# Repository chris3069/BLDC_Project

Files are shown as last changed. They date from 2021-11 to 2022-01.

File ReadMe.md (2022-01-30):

# BLDC source code and electronics

# Electronics
## Schematics:

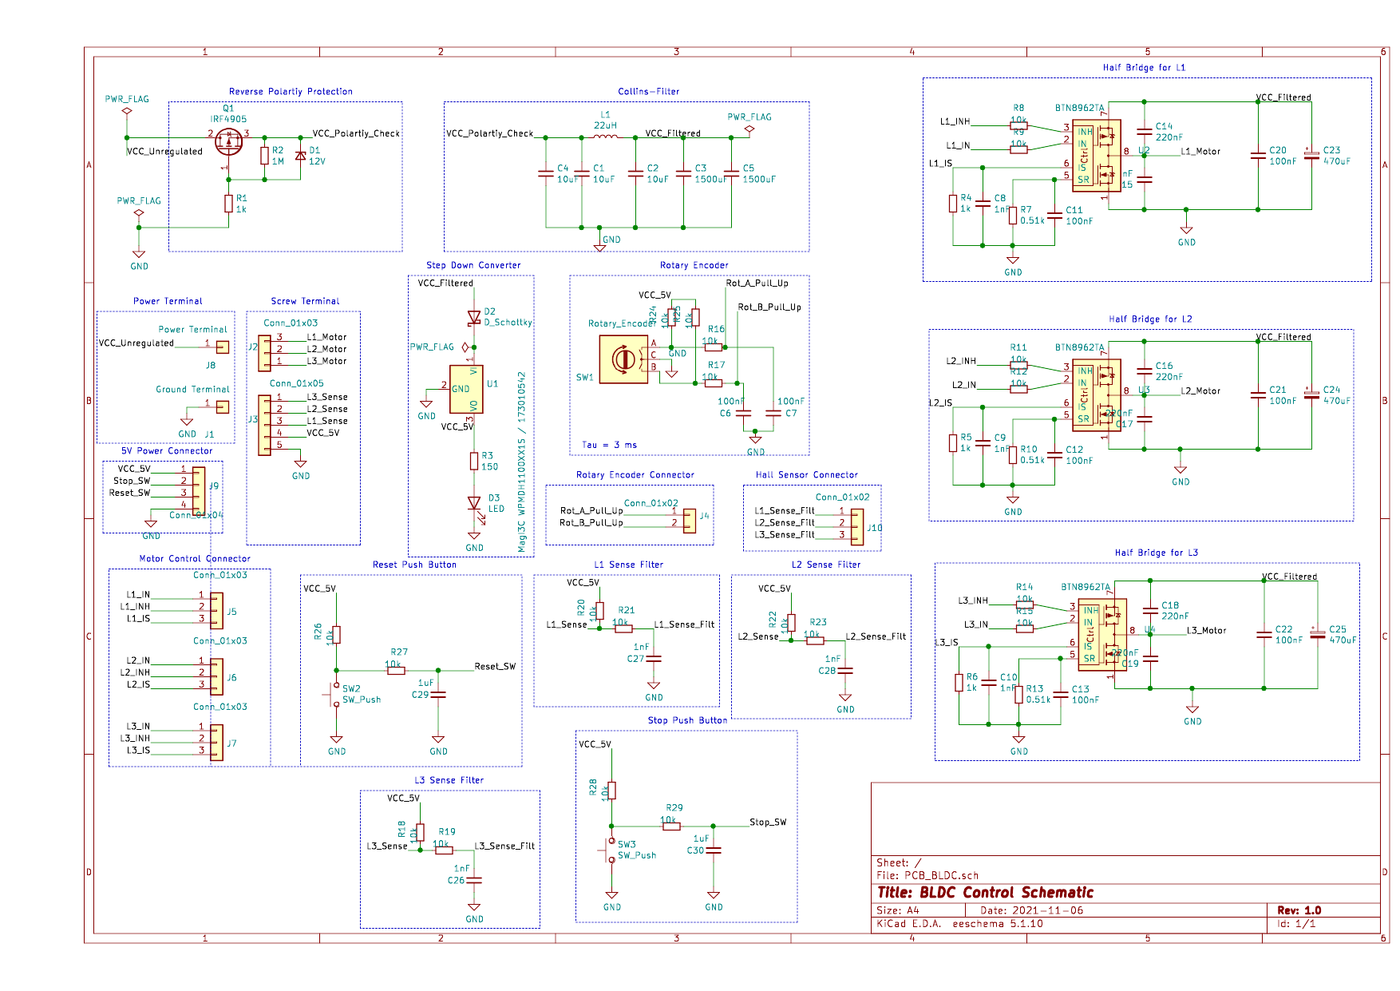
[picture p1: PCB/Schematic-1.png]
Schematic


## Design and Routing

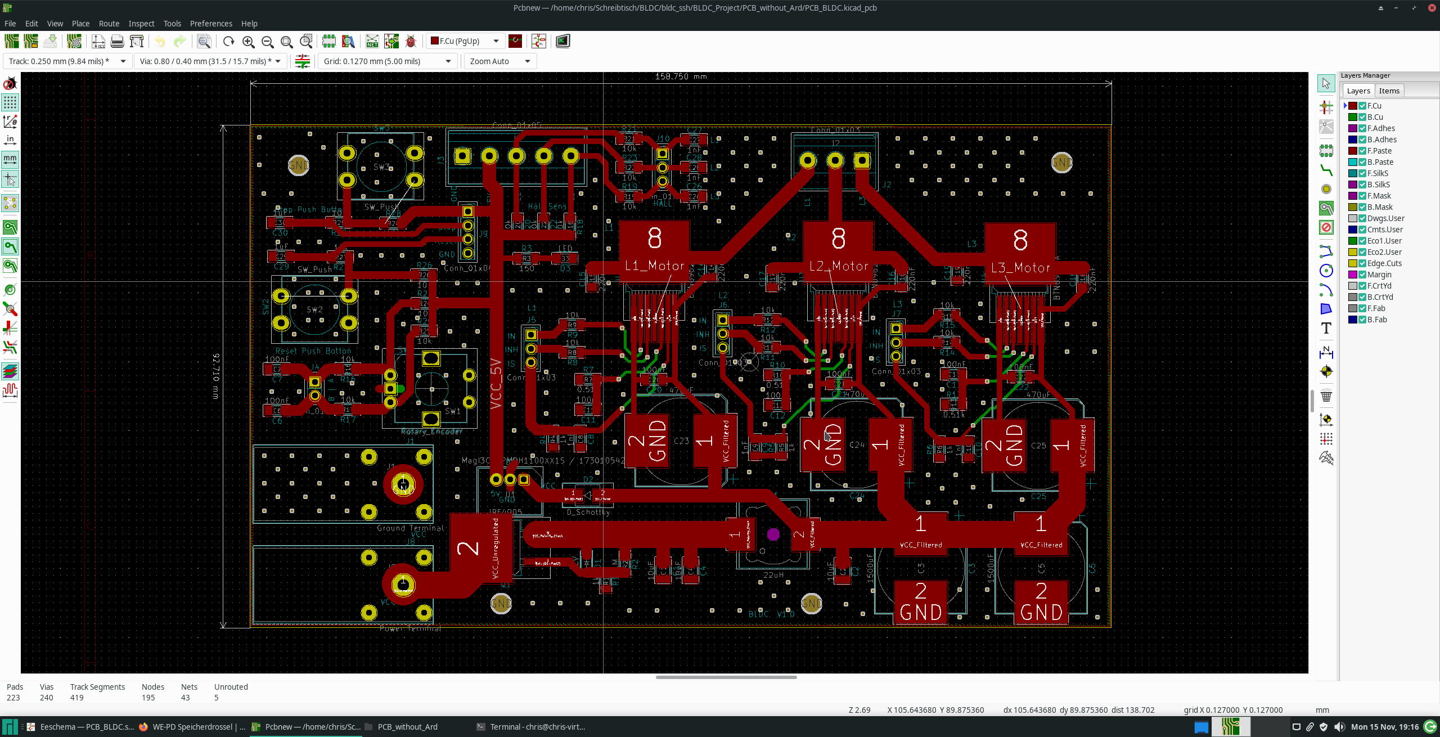
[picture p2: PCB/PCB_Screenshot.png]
PCB_Routing 2D Schematic


## 3D Electric Design:
### Frontside 
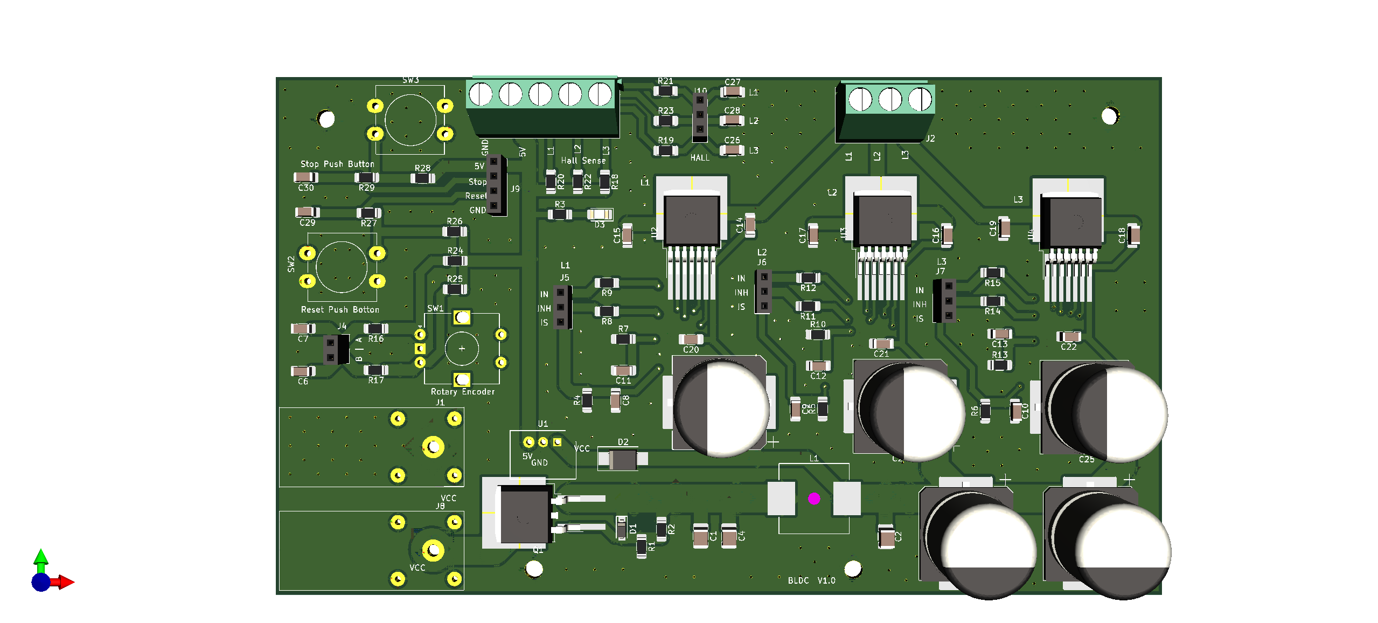
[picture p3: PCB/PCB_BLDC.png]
Frontside

### Backside
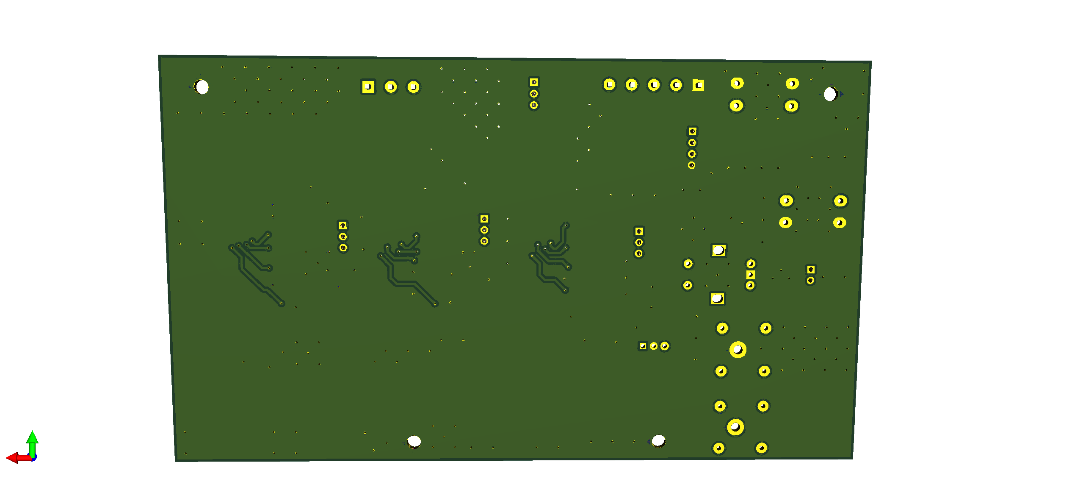
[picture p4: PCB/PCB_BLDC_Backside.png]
Backside


# SW

## Open Loop Control

## Closed Loop Control

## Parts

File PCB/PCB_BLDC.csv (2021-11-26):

Source: | /home/chris/Schreibtisch/BLDC/bldc_ssh/BLDC_Project/PCB_without_Ard/PCB_BLDC.sch
Date: | Mon 15 Nov 2021 06:43:22 PM CET
Tool: | Eeschema 5.1.10
Generator: | /usr/share/kicad/plugins/bom_csv_grouped_by_value.py
Component Count: | 81
Individual Components:
Item | Qty | Reference(s) | Value | LibPart | Footprint | Datasheet
 |  | C1 | 10uF | Device:C_Small | Capacitor_SMD:C_1210_3225Metric_Pad1.33x2.70mm_HandSolder | ~
 |  | C2 | 10uF | Device:C_Small | Capacitor_SMD:C_1210_3225Metric_Pad1.33x2.70mm_HandSolder | ~
 |  | C3 | 1500uF | Device:C_Small | Capacitor_SMD:CP_Elec_16x17.5 | ~
 |  | C4 | 10uF | Device:C_Small | Capacitor_SMD:C_1210_3225Metric_Pad1.33x2.70mm_HandSolder | ~
 |  | C5 | 1500uF | Device:C_Small | Capacitor_SMD:CP_Elec_16x17.5 | ~
 |  | C6 | 100nF | Device:C_Small | Capacitor_SMD:C_1206_3216Metric_Pad1.33x1.80mm_HandSolder | ~
 |  | C7 | 100nF | Device:C_Small | Capacitor_SMD:C_1206_3216Metric_Pad1.33x1.80mm_HandSolder | ~
 |  | C8 | 1nF | Device:C_Small | Capacitor_SMD:C_1206_3216Metric_Pad1.33x1.80mm_HandSolder | ~
 |  | C9 | 1nF | Device:C_Small | Capacitor_SMD:C_1206_3216Metric_Pad1.33x1.80mm_HandSolder | ~
 |  | C10 | 1nF | Device:C_Small | Capacitor_SMD:C_1206_3216Metric_Pad1.33x1.80mm_HandSolder | ~
 |  | C11 | 100nF | Device:C_Small | Capacitor_SMD:C_1206_3216Metric_Pad1.33x1.80mm_HandSolder | ~
 |  | C12 | 100nF | Device:C_Small | Capacitor_SMD:C_1206_3216Metric_Pad1.33x1.80mm_HandSolder | ~
 |  | C13 | 100nF | Device:C_Small | Capacitor_SMD:C_1206_3216Metric_Pad1.33x1.80mm_HandSolder | ~
 |  | C14 | 220nF | Device:C_Small | Capacitor_SMD:C_1206_3216Metric_Pad1.33x1.80mm_HandSolder | ~
 |  | C15 | 220nF | Device:C_Small | Capacitor_SMD:C_1206_3216Metric_Pad1.33x1.80mm_HandSolder | ~
 |  | C16 | 220nF | Device:C_Small | Capacitor_SMD:C_1206_3216Metric_Pad1.33x1.80mm_HandSolder | ~
 |  | C17 | 220nF | Device:C_Small | Capacitor_SMD:C_1206_3216Metric_Pad1.33x1.80mm_HandSolder | ~
 |  | C18 | 220nF | Device:C_Small | Capacitor_SMD:C_1206_3216Metric_Pad1.33x1.80mm_HandSolder | ~
 |  | C19 | 220nF | Device:C_Small | Capacitor_SMD:C_1206_3216Metric_Pad1.33x1.80mm_HandSolder | ~
 |  | C20 | 100nF | Device:C_Small | Capacitor_SMD:C_1206_3216Metric_Pad1.33x1.80mm_HandSolder | ~
 |  | C21 | 100nF | Device:C_Small | Capacitor_SMD:C_1206_3216Metric_Pad1.33x1.80mm_HandSolder | ~
 |  | C22 | 100nF | Device:C_Small | Capacitor_SMD:C_1206_3216Metric_Pad1.33x1.80mm_HandSolder | ~
 |  | C23 | 470uF | Device:CP_Small | Capacitor_SMD:CP_Elec_16x17.5 | ~
 |  | C24 | 470uF | Device:CP_Small | Capacitor_SMD:CP_Elec_16x17.5 | ~
 |  | C25 | 470uF | Device:CP_Small | Capacitor_SMD:CP_Elec_16x17.5 | ~
 |  | C26 | 1nF | Device:C_Small | Capacitor_SMD:C_1206_3216Metric_Pad1.33x1.80mm_HandSolder | ~
 |  | C27 | 1nF | Device:C_Small | Capacitor_SMD:C_1206_3216Metric_Pad1.33x1.80mm_HandSolder | ~
 |  | C28 | 1nF | Device:C_Small | Capacitor_SMD:C_1206_3216Metric_Pad1.33x1.80mm_HandSolder | ~
 |  | C29 | 1uF | Device:C_Small | Capacitor_SMD:C_1206_3216Metric_Pad1.33x1.80mm_HandSolder | ~
 |  | C30 | 1uF | Device:C_Small | Capacitor_SMD:C_1206_3216Metric_Pad1.33x1.80mm_HandSolder | ~
 |  | D1 | 12V | Device:D_Zener_Small | Diode_SMD:D_SOD-123 | ~
 |  | D2 | D_Schottky | Device:D_Schottky | Diode_SMD:D_SMB_Handsoldering | ~
 |  | D3 | LED | Device:LED | LED_SMD:LED_1206_3216Metric_Pad1.42x1.75mm_HandSolder | ~
 |  | J1 | Ground Terminal | Connector_Generic:Conn_01x01 | Connector:CalTest_CT3151 | ~
 |  | J2 | Conn_01x03 | Connector_Generic:Conn_01x03 | TerminalBlock_Phoenix:TerminalBlock_Phoenix_MKDS-1,5-3_1x03_P5.00mm_Horizontal | ~
 |  | J3 | Conn_01x05 | Connector_Generic:Conn_01x05 | TerminalBlock_Phoenix:TerminalBlock_Phoenix_MKDS-1,5-5_1x05_P5.00mm_Horizontal | ~
 |  | J4 | Conn_01x02 | Connector_Generic:Conn_01x02 | Connector_PinSocket_2.54mm:PinSocket_1x02_P2.54mm_Vertical | ~
 |  | J5 | Conn_01x03 | Connector_Generic:Conn_01x03 | Connector_PinSocket_2.54mm:PinSocket_1x03_P2.54mm_Vertical | ~
 |  | J6 | Conn_01x03 | Connector_Generic:Conn_01x03 | Connector_PinSocket_2.54mm:PinSocket_1x03_P2.54mm_Vertical | ~
 |  | J7 | Conn_01x03 | Connector_Generic:Conn_01x03 | Connector_PinSocket_2.54mm:PinSocket_1x03_P2.54mm_Vertical | ~
 |  | J8 | Power Terminal | Connector_Generic:Conn_01x01 | Connector:CalTest_CT3151 | ~
 |  | J9 | Conn_01x04 | Connector_Generic:Conn_01x04 | Connector_PinSocket_2.54mm:PinSocket_1x04_P2.54mm_Vertical | ~
 |  | J10 | Conn_01x02 | Connector_Generic:Conn_01x03 | Connector_PinSocket_2.54mm:PinSocket_1x03_P2.54mm_Vertical | ~
 |  | L1 | 22uH | Device:L | Inductor_SMD:L_Wuerth_WE-PD-Typ-LS_Handsoldering | ~
 |  | Q1 | IRF4905 | Transistor_FET:IRF4905 | Package_TO_SOT_SMD:TO-263-2 | http://www.infineon.com/dgdl/irf4905.pdf?fileId=5546d462533600a4015355e32165197c
 |  | R1 | 1k | Device:R_Small | Resistor_SMD:R_1206_3216Metric_Pad1.30x1.75mm_HandSolder | ~
 |  | R2 | 1M | Device:R_Small | Resistor_SMD:R_1206_3216Metric_Pad1.30x1.75mm_HandSolder | ~
 |  | R3 | 150 | Device:R_Small | Resistor_SMD:R_1206_3216Metric_Pad1.30x1.75mm_HandSolder | ~
 |  | R4 | 1k | Device:R_Small | Resistor_SMD:R_1206_3216Metric_Pad1.30x1.75mm_HandSolder | ~
 |  | R5 | 1k | Device:R_Small | Resistor_SMD:R_1206_3216Metric_Pad1.30x1.75mm_HandSolder | ~
 |  | R6 | 1k | Device:R_Small | Resistor_SMD:R_1206_3216Metric_Pad1.30x1.75mm_HandSolder | ~
 |  | R7 | 0.51k | Device:R_Small | Resistor_SMD:R_1206_3216Metric_Pad1.30x1.75mm_HandSolder | ~
 |  | R8 | 10k | Device:R_Small | Resistor_SMD:R_1206_3216Metric_Pad1.30x1.75mm_HandSolder | ~
 |  | R9 | 10k | Device:R_Small | Resistor_SMD:R_1206_3216Metric_Pad1.30x1.75mm_HandSolder | ~
 |  | R10 | 0.51k | Device:R_Small | Resistor_SMD:R_1206_3216Metric_Pad1.30x1.75mm_HandSolder | ~
 |  | R11 | 10k | Device:R_Small | Resistor_SMD:R_1206_3216Metric_Pad1.30x1.75mm_HandSolder | ~
 |  | R12 | 10k | Device:R_Small | Resistor_SMD:R_1206_3216Metric_Pad1.30x1.75mm_HandSolder | ~
 |  | R13 | 0.51k | Device:R_Small | Resistor_SMD:R_1206_3216Metric_Pad1.30x1.75mm_HandSolder | ~
 |  | R14 | 10k | Device:R_Small | Resistor_SMD:R_1206_3216Metric_Pad1.30x1.75mm_HandSolder | ~
 |  | R15 | 10k | Device:R_Small | Resistor_SMD:R_1206_3216Metric_Pad1.30x1.75mm_HandSolder | ~
 |  | R16 | 10k | Device:R_Small | Resistor_SMD:R_1206_3216Metric_Pad1.30x1.75mm_HandSolder | ~
 |  | R17 | 10k | Device:R_Small | Resistor_SMD:R_1206_3216Metric_Pad1.30x1.75mm_HandSolder | ~
 |  | R18 | 10k | Device:R_Small | Resistor_SMD:R_1206_3216Metric_Pad1.30x1.75mm_HandSolder | ~
 |  | R19 | 10k | Device:R_Small | Resistor_SMD:R_1206_3216Metric_Pad1.30x1.75mm_HandSolder | ~
 |  | R20 | 10k | Device:R_Small | Resistor_SMD:R_1206_3216Metric_Pad1.30x1.75mm_HandSolder | ~
 |  | R21 | 10k | Device:R_Small | Resistor_SMD:R_1206_3216Metric_Pad1.30x1.75mm_HandSolder | ~
 |  | R22 | 10k | Device:R_Small | Resistor_SMD:R_1206_3216Metric_Pad1.30x1.75mm_HandSolder | ~
 |  | R23 | 10k | Device:R_Small | Resistor_SMD:R_1206_3216Metric_Pad1.30x1.75mm_HandSolder | ~
 |  | R24 | 10k | Device:R_Small | Resistor_SMD:R_1206_3216Metric_Pad1.30x1.75mm_HandSolder | ~
 |  | R25 | 10k | Device:R_Small | Resistor_SMD:R_1206_3216Metric_Pad1.30x1.75mm_HandSolder | ~
 |  | R26 | 10k | Device:R_Small | Resistor_SMD:R_1206_3216Metric_Pad1.30x1.75mm_HandSolder | ~
 |  | R27 | 10k | Device:R_Small | Resistor_SMD:R_1206_3216Metric_Pad1.30x1.75mm_HandSolder | ~
 |  | R28 | 10k | Device:R_Small | Resistor_SMD:R_1206_3216Metric_Pad1.30x1.75mm_HandSolder | ~
 |  | R29 | 10k | Device:R_Small | Resistor_SMD:R_1206_3216Metric_Pad1.30x1.75mm_HandSolder | ~
 |  | SW1 | Rotary_Encoder | Device:Rotary_Encoder | Rotary_Encoder:RotaryEncoder_Alps_EC12E-Switch_Vertical_H20mm | ~
 |  | SW2 | SW_Push | Switch:SW_Push | Button_Switch_THT:SW_PUSH-12mm_Wuerth-430476085716 | ~
 |  | SW3 | SW_Push | Switch:SW_Push | Button_Switch_THT:SW_PUSH-12mm_Wuerth-430476085716 | ~
 |  | U1 | MagI3C WPMDH1100XX1S / 173010542 | Regulator_Linear:LF15_TO220 | Package_SIP:SIP3_11.6x8.5mm | http://www.st.com/content/ccc/resource/technical/document/datasheet/c4/0e/7e/2a/be/bc/4c/bd/CD00000546.pdf/files/CD00000546.pdf/jcr:content/translations/en.CD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
 |  | U2 | BTN8962TA | btn8962ta:BTN8962TA | Package_TO_SOT_SMD:TO-263-7_TabPin8
 |  | U3 | BTN8962TA | btn8962ta:BTN8962TA | Package_TO_SOT_SMD:TO-263-7_TabPin8
 |  | U4 | BTN8962TA | btn8962ta:BTN8962TA | Package_TO_SOT_SMD:TO-263-7_TabPin8
Collated Components:
Item | Qty | Reference(s) | Value | LibPart | Footprint | Datasheet
1 | 3 | C1, C2, C4 | 10uF | Device:C_Small | Capacitor_SMD:C_1210_3225Metric_Pad1.33x2.70mm_HandSolder | ~
2 | 2 | C3, C5 | 1500uF | Device:C_Small | Capacitor_SMD:CP_Elec_16x17.5 | ~
3 | 8 | C6, C7, C11, C12, C13, C20, C21, C22 | 100nF | Device:C_Small | Capacitor_SMD:C_1206_3216Metric_Pad1.33x1.80mm_HandSolder | ~
4 | 6 | C8, C9, C10, C26, C27, C28 | 1nF | Device:C_Small | Capacitor_SMD:C_1206_3216Metric_Pad1.33x1.80mm_HandSolder | ~
5 | 6 | C14, C15, C16, C17, C18, C19 | 220nF | Device:C_Small | Capacitor_SMD:C_1206_3216Metric_Pad1.33x1.80mm_HandSolder | ~
6 | 3 | C23, C24, C25 | 470uF | Device:CP_Small | Capacitor_SMD:CP_Elec_16x17.5 | ~
7 | 2 | C29, C30 | 1uF | Device:C_Small | Capacitor_SMD:C_1206_3216Metric_Pad1.33x1.80mm_HandSolder | ~
8 | 1 | D1 | 12V | Device:D_Zener_Small | Diode_SMD:D_SOD-123 | ~
9 | 1 | D2 | D_Schottky | Device:D_Schottky | Diode_SMD:D_SMB_Handsoldering | ~
10 | 1 | D3 | LED | Device:LED | LED_SMD:LED_1206_3216Metric_Pad1.42x1.75mm_HandSolder | ~
11 | 1 | J1 | Ground Terminal | Connector_Generic:Conn_01x01 | Connector:CalTest_CT3151 | ~
12 | 1 | J2 | Conn_01x03 | Connector_Generic:Conn_01x03 | TerminalBlock_Phoenix:TerminalBlock_Phoenix_MKDS-1,5-3_1x03_P5.00mm_Horizontal | ~
13 | 1 | J3 | Conn_01x05 | Connector_Generic:Conn_01x05 | TerminalBlock_Phoenix:TerminalBlock_Phoenix_MKDS-1,5-5_1x05_P5.00mm_Horizontal | ~
14 | 1 | J4 | Conn_01x02 | Connector_Generic:Conn_01x02 | Connector_PinSocket_2.54mm:PinSocket_1x02_P2.54mm_Vertical | ~
15 | 3 | J5, J6, J7 | Conn_01x03 | Connector_Generic:Conn_01x03 | Connector_PinSocket_2.54mm:PinSocket_1x03_P2.54mm_Vertical | ~
16 | 1 | J8 | Power Terminal | Connector_Generic:Conn_01x01 | Connector:CalTest_CT3151 | ~
17 | 1 | J9 | Conn_01x04 | Connector_Generic:Conn_01x04 | Connector_PinSocket_2.54mm:PinSocket_1x04_P2.54mm_Vertical | ~
18 | 1 | J10 | Conn_01x02 | Connector_Generic:Conn_01x03 | Connector_PinSocket_2.54mm:PinSocket_1x03_P2.54mm_Vertical | ~
19 | 1 | L1 | 22uH | Device:L | Inductor_SMD:L_Wuerth_WE-PD-Typ-LS_Handsoldering | ~
20 | 1 | Q1 | IRF4905 | Transistor_FET:IRF4905 | Package_TO_SOT_SMD:TO-263-2 | http://www.infineon.com/dgdl/irf4905.pdf?fileId=5546d462533600a4015355e32165197c
21 | 4 | R1, R4, R5, R6 | 1k | Device:R_Small | Resistor_SMD:R_1206_3216Metric_Pad1.30x1.75mm_HandSolder | ~
22 | 1 | R2 | 1M | Device:R_Small | Resistor_SMD:R_1206_3216Metric_Pad1.30x1.75mm_HandSolder | ~
23 | 1 | R3 | 150 | Device:R_Small | Resistor_SMD:R_1206_3216Metric_Pad1.30x1.75mm_HandSolder | ~
24 | 3 | R7, R10, R13 | 0.51k | Device:R_Small | Resistor_SMD:R_1206_3216Metric_Pad1.30x1.75mm_HandSolder | ~
25 | 20 | R8, R9, R11, R12, R14, R15, R16, R17, R18, R19, R20, R21, R22, R23, R24, R25, R26, R27, R28, R29 | 10k | Device:R_Small | Resistor_SMD:R_1206_3216Metric_Pad1.30x1.75mm_HandSolder | ~
26 | 1 | SW1 | Rotary_Encoder | Device:Rotary_Encoder | Rotary_Encoder:RotaryEncoder_Alps_EC12E-Switch_Vertical_H20mm | ~
27 | 2 | SW2, SW3 | SW_Push | Switch:SW_Push | Button_Switch_THT:SW_PUSH-12mm_Wuerth-430476085716 | ~
28 | 1 | U1 | MagI3C WPMDH1100XX1S / 173010542 | Regulator_Linear:LF15_TO220 | Package_SIP:SIP3_11.6x8.5mm | http://www.st.com/content/ccc/resource/technical/document/datasheet/c4/0e/7e/2a/be/bc/4c/bd/CD00000546.pdf/files/CD00000546.pdf/jcr:content/translations/en.CD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
29 | 3 | U2, U3, U4 | BTN8962TA | btn8962ta:BTN8962TA | Package_TO_SOT_SMD:TO-263-7_TabPin8

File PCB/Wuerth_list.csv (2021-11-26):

Collated Components:
Item | Qty | Reference(s) | Value | LibPart | Footprint | Seller
1 | 3 | C1, C2, C4 | 10uF | Device:C_Small | Capacitor_SMD:C_1210_3225Metric_Pad1.33x2.70mm_HandSolder | https://www.we-online.com/katalog/de/WCAP-CSGP-50VDC | 885012209073
2 | 2 | C3, C5 | 1500uF | Device:C_Small | Capacitor_SMD:CP_Elec_16x17.5 | https://www.we-online.com/katalog/de/WCAP-ASLL | 865060563012
3 | 11 | C6, C7, C11, C12, C13 | 100nF | Device:C_Small | Capacitor_SMD:C_1206_3216Metric_Pad1.33x1.80mm_HandSolder | https://www.we-online.com/katalog/de/WCAP-CSGP-50VDC | 885012208087
4 | 6 | C8, C9, C10, C26, C27, C28 | 1nF | Device:C_Small | Capacitor_SMD:C_1206_3216Metric_Pad1.33x1.80mm_HandSolder | https://www.we-online.com/katalog/de/WCAP-CSGP-50VDC | 885012008049
5 | 6 | C14, C15, C16, C17, C18, C19 | 220nF | Device:C_Small | Capacitor_SMD:C_1206_3216Metric_Pad1.33x1.80mm_HandSolder | https://www.we-online.com/katalog/de/WCAP-CSGP-50VDC | 885012208089
7 | 3 | C23, C24, C25 | 470nF | Device:C_Small | Capacitor_SMD:C_Elec_5x5.4 | https://www.we-online.com/katalog/de/WCAP-ASLL | 865060763010
10 | 1 | D3 | LED | Device:LED | LED_SMD:LED_1206_3216Metric_Pad1.42x1.75mm_HandSolder | https://www.we-online.com/katalog/de/WL-SMCW#150120GS75000 | 150120GS75000
17 | 1 | L1 | 22uH | Device:L | Inductor_SMD:L_Wuerth_WE-PD-Typ-LS_Handsoldering | fire | 7447709220
24 | 1 | SW1 | Rotary_Encoder | Device:Rotary_Encoder | Rotary_Encoder:RotaryEncoder_Alps_EC12E-Switch_Vertical_H20mm | https://www.we-online.com/katalog/de/ENTV_11X13_75X26_6_THT_SHAFT_WITH_BUSHING#482020514001 | 482020514001
25 | 1 | U1 | MagI3C WPMDH1100XX1S / 173010542 | Regulator_Linear:LF15_TO220 | Package_SIP:SIP3_11.6x8.5mm | https://www.we-online.com/katalog/de/MAGIC_FDSM_FIXED_OUTPUT_VOLTAGE | 173010542
12 | 1 | J2 | Conn_01x03 | Connector_Generic:Conn_01x03 | TerminalBlock_Phoenix:TerminalBlock_Phoenix_MKDS-1,5-3_1x03_P5.00mm_Horizontal | https://www.we-online.com/katalog/de/PHD_2_54_SOCKET_HEADER_6130XX11821 | 61300211821 | 3 Pins
13 | 1 | J3 | Conn_01x05 | Connector_Generic:Conn_01x05 | TerminalBlock_Phoenix:TerminalBlock_Phoenix_MKDS-1,5-5_1x05_P5.00mm_Horizontal | https://www.we-online.com/katalog/de/PHD_2_54_SOCKET_HEADER_6130XX11821 | 61300211821 | 5 Pins
14 | 2 | J4, J9 | Conn_01x02 | Connector_Generic:Conn_01x02 | Connector_PinSocket_2.54mm:PinSocket_1x02_P2.54mm_Vertical | https://www.we-online.com/katalog/de/PHD_2_54_SOCKET_HEADER_6130XX11821 | 61300211821 | 2 Pins
15 | 3 | J5, J6, J7 | Conn_01x04 | Connector_Generic:Conn_01x04 | Connector_PinSocket_2.54mm:PinSocket_1x04_P2.54mm_Vertical | https://www.we-online.com/katalog/de/PHD_2_54_SOCKET_HEADER_6130XX11821 | 61300211821 | 4 Pins
 |  |  |  | Push Button | https://www.we-online.com/katalog/de/TATV_12X12_THT_WASHABLE_4304X60XX7X6 |  | 430476085716

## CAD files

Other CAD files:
kicad-footprints-5.1.10/Sources/Inductor_SMD/L_Coilcraft_LPS5030.FCStd
kicad-footprints-5.1.10/Sources/Package_LGA/Infineon_PG-LLGA-5-1.FCStd
kicad-footprints-5.1.10/Sources/Package_SON/X2SON-4_1x1mm_P0.65mm.fcstd
kicad-footprints-5.1.10/Sources/Package_TO_SOT_THT/sod-70.fcstd
kicad-footprints-5.1.10/Sources/Inductor_SMD/L_Wuerth_WE-TPC-3816.FCStd
kicad-footprints-5.1.10/Sources/Package_TO_SOT_THT/sod-70_P5.08mm.fcstd

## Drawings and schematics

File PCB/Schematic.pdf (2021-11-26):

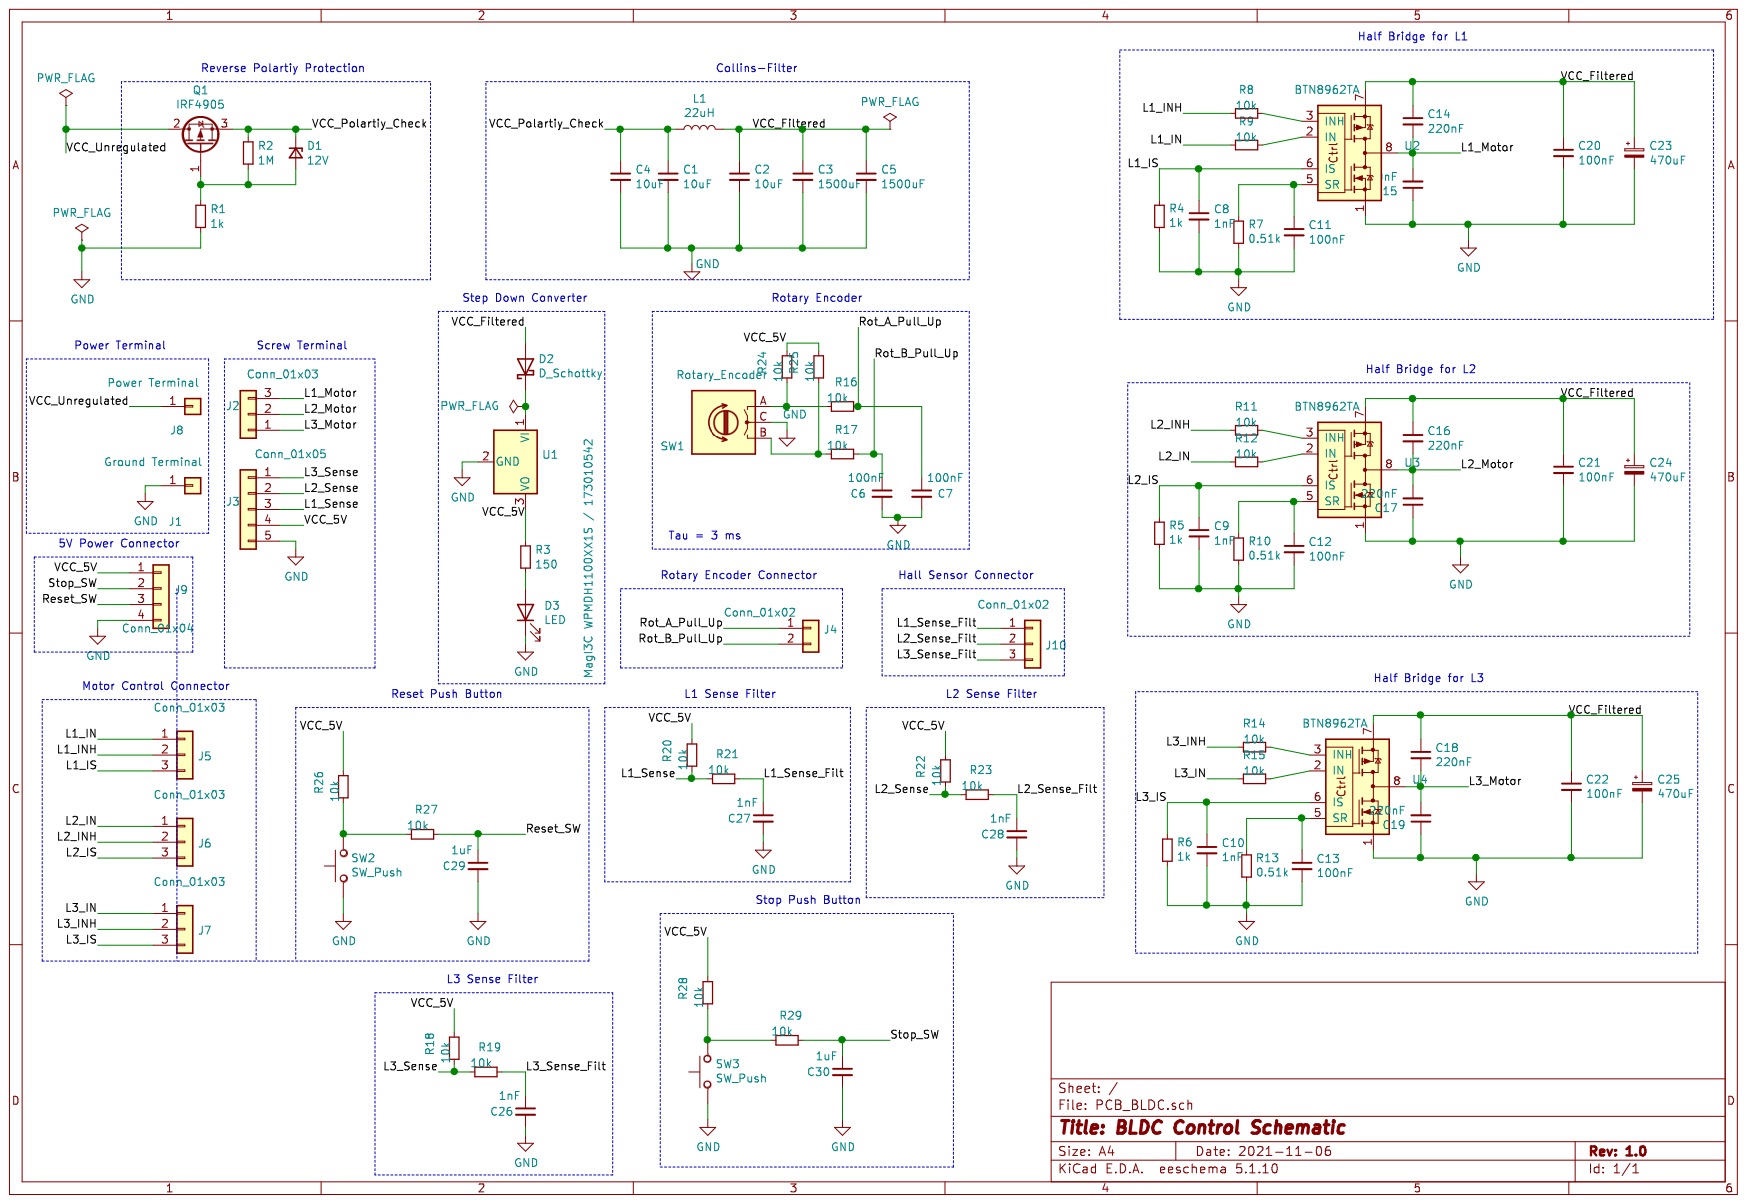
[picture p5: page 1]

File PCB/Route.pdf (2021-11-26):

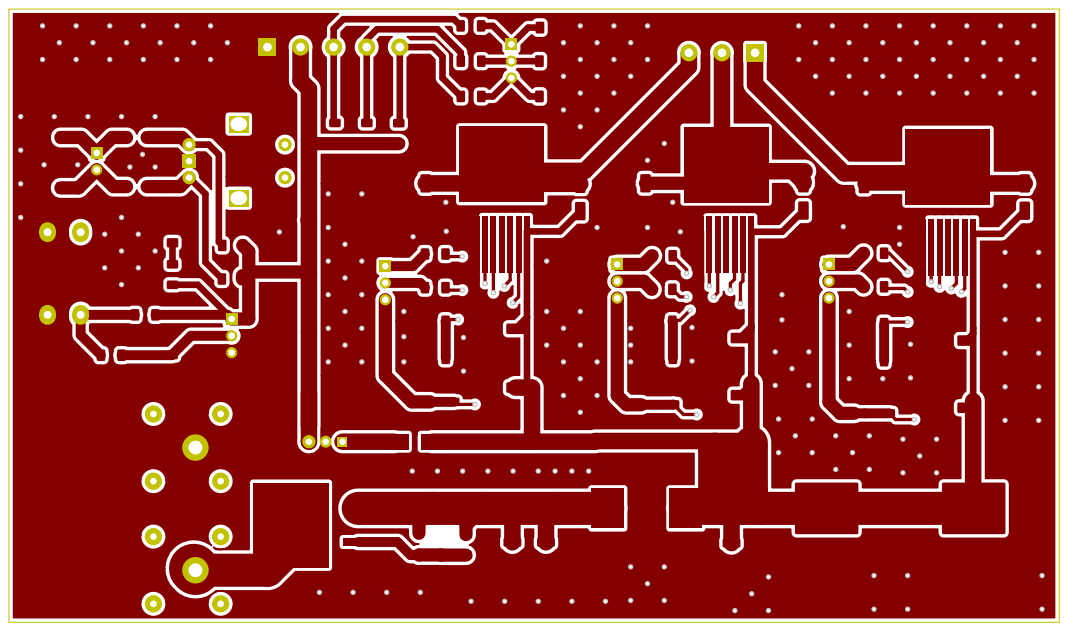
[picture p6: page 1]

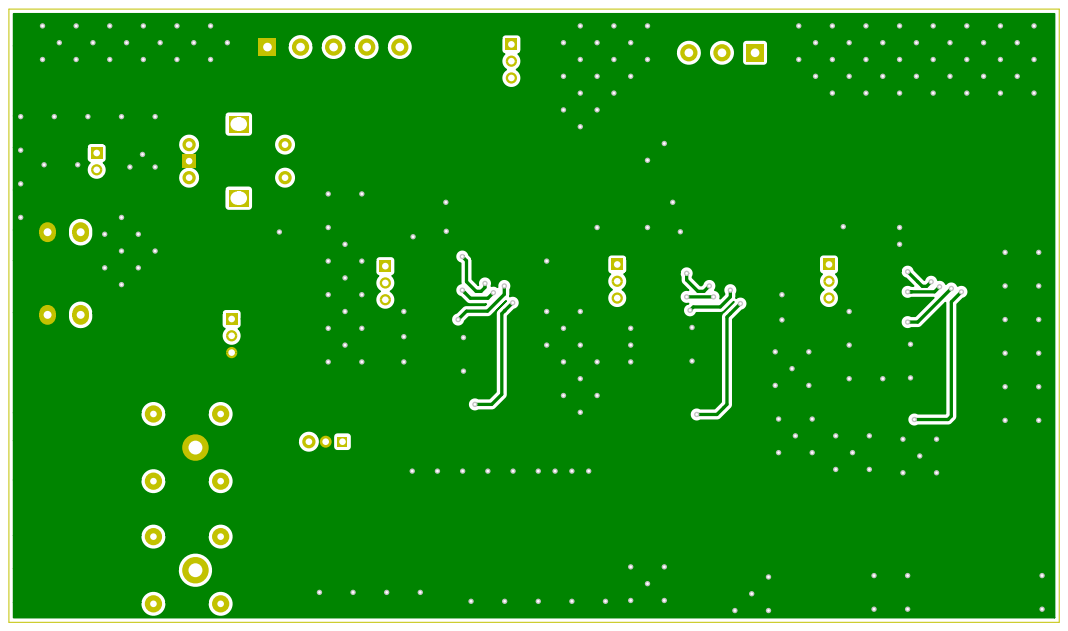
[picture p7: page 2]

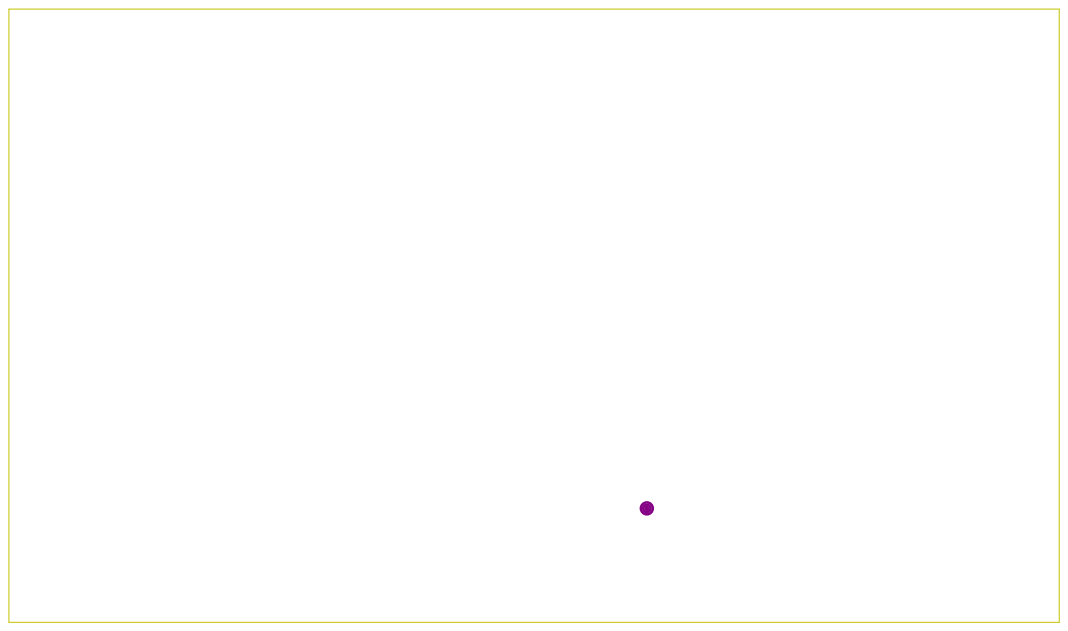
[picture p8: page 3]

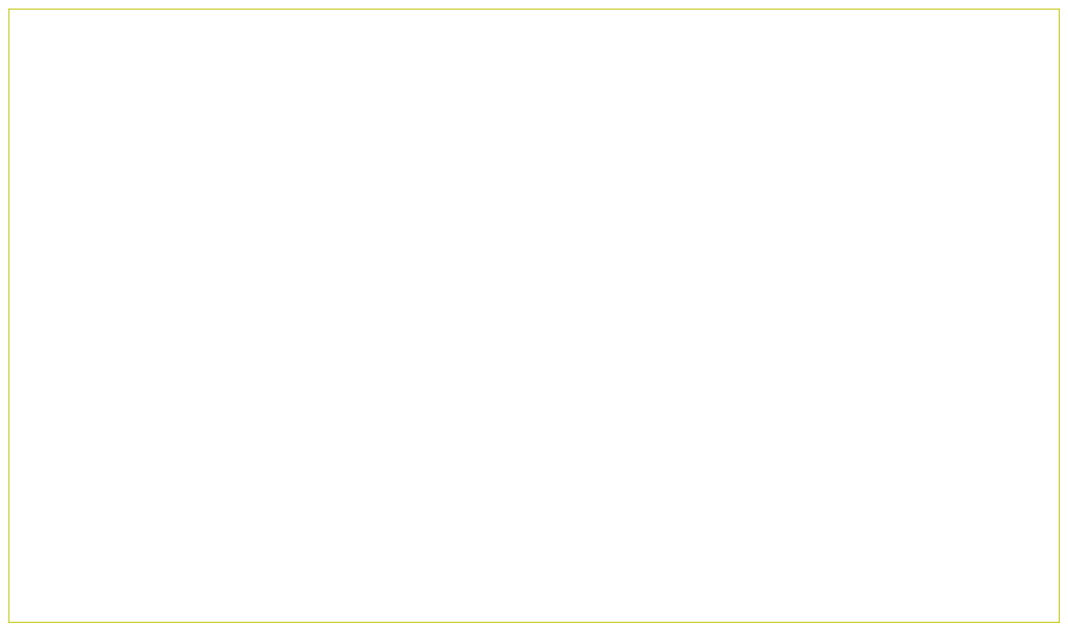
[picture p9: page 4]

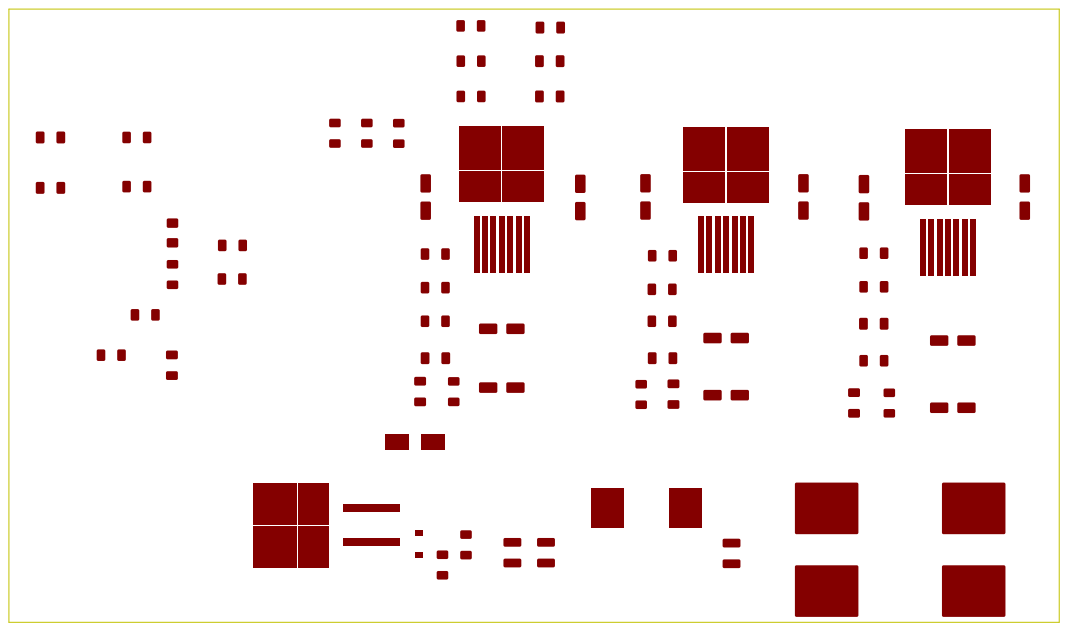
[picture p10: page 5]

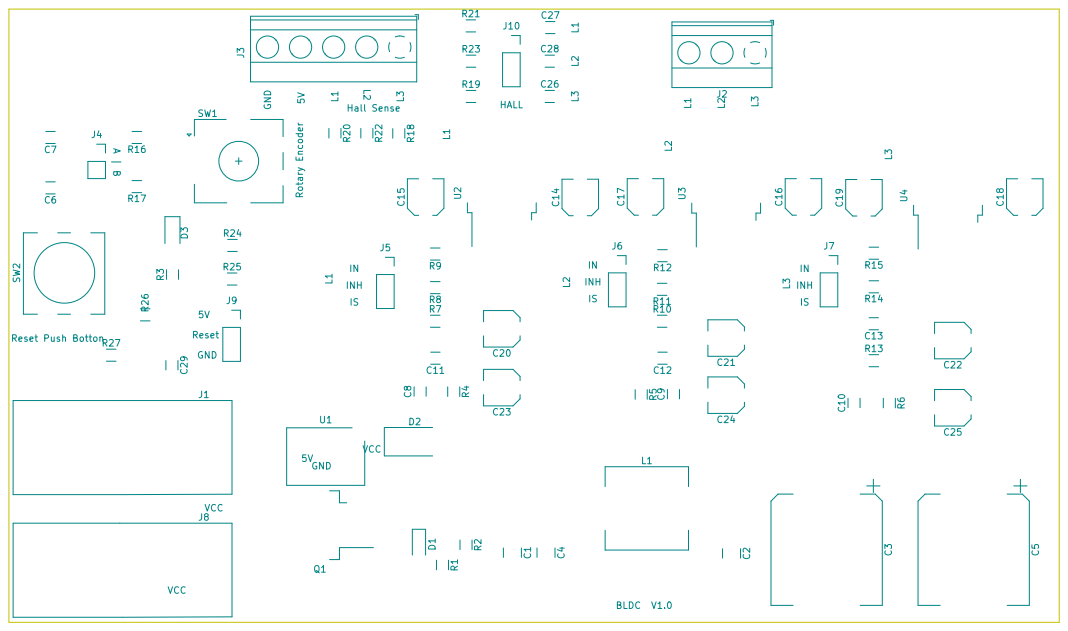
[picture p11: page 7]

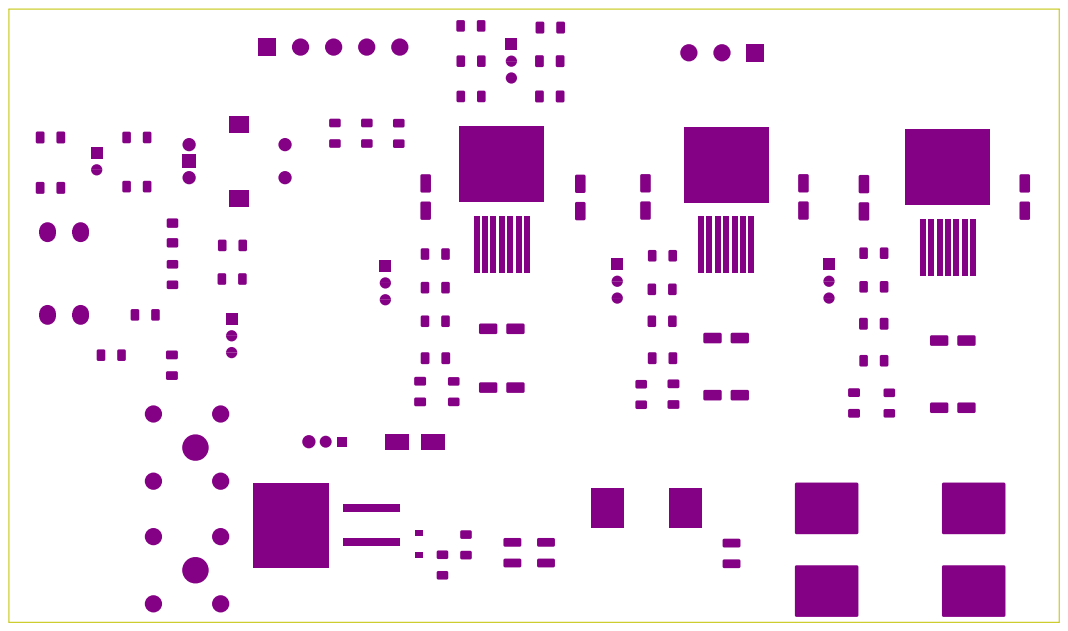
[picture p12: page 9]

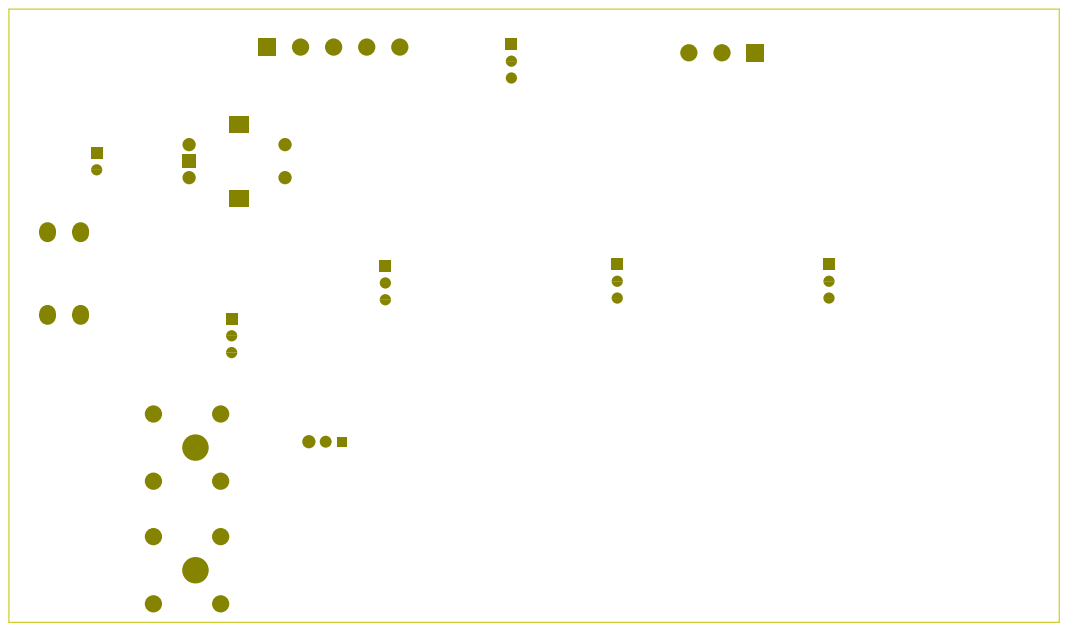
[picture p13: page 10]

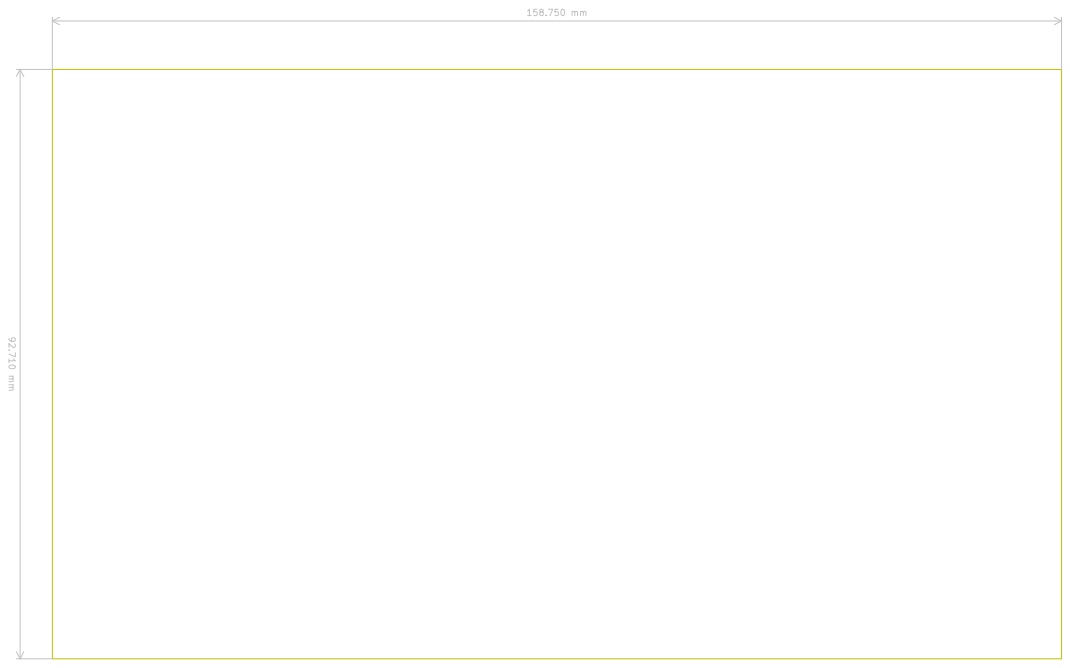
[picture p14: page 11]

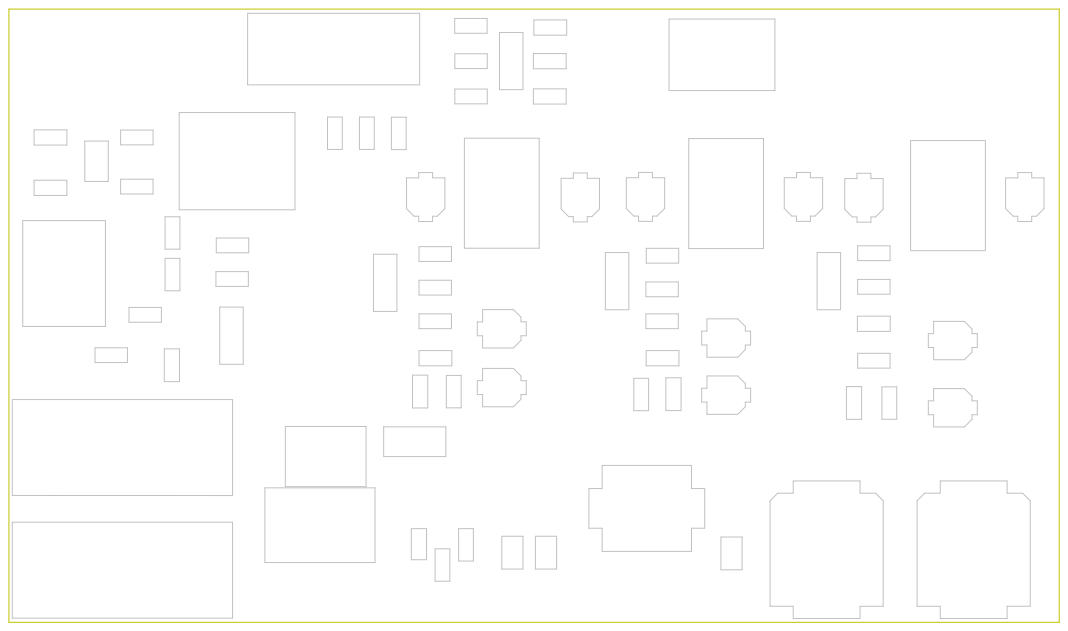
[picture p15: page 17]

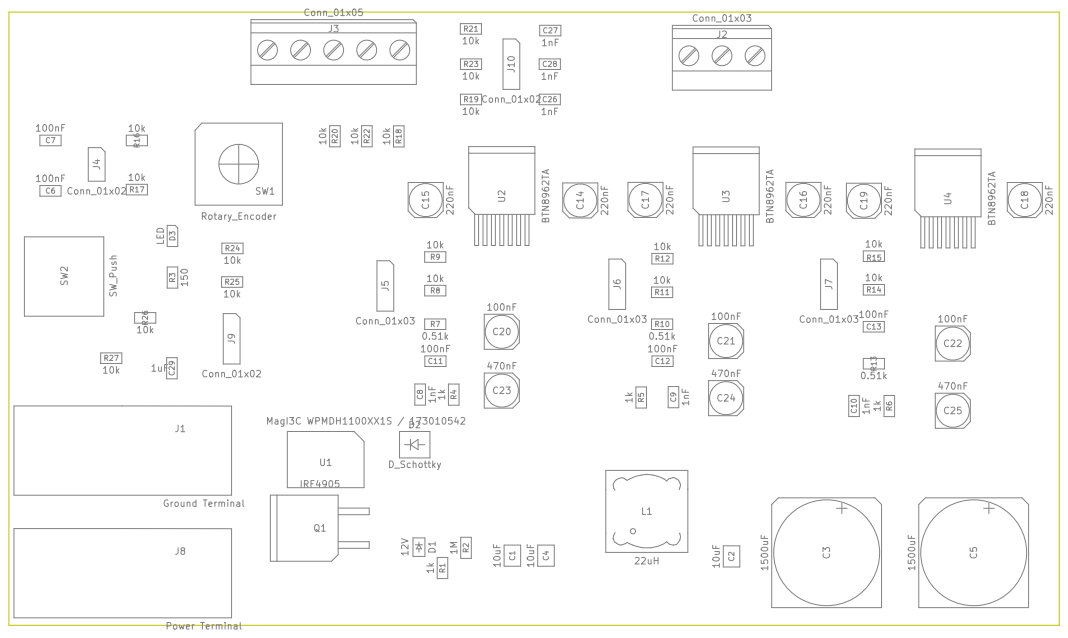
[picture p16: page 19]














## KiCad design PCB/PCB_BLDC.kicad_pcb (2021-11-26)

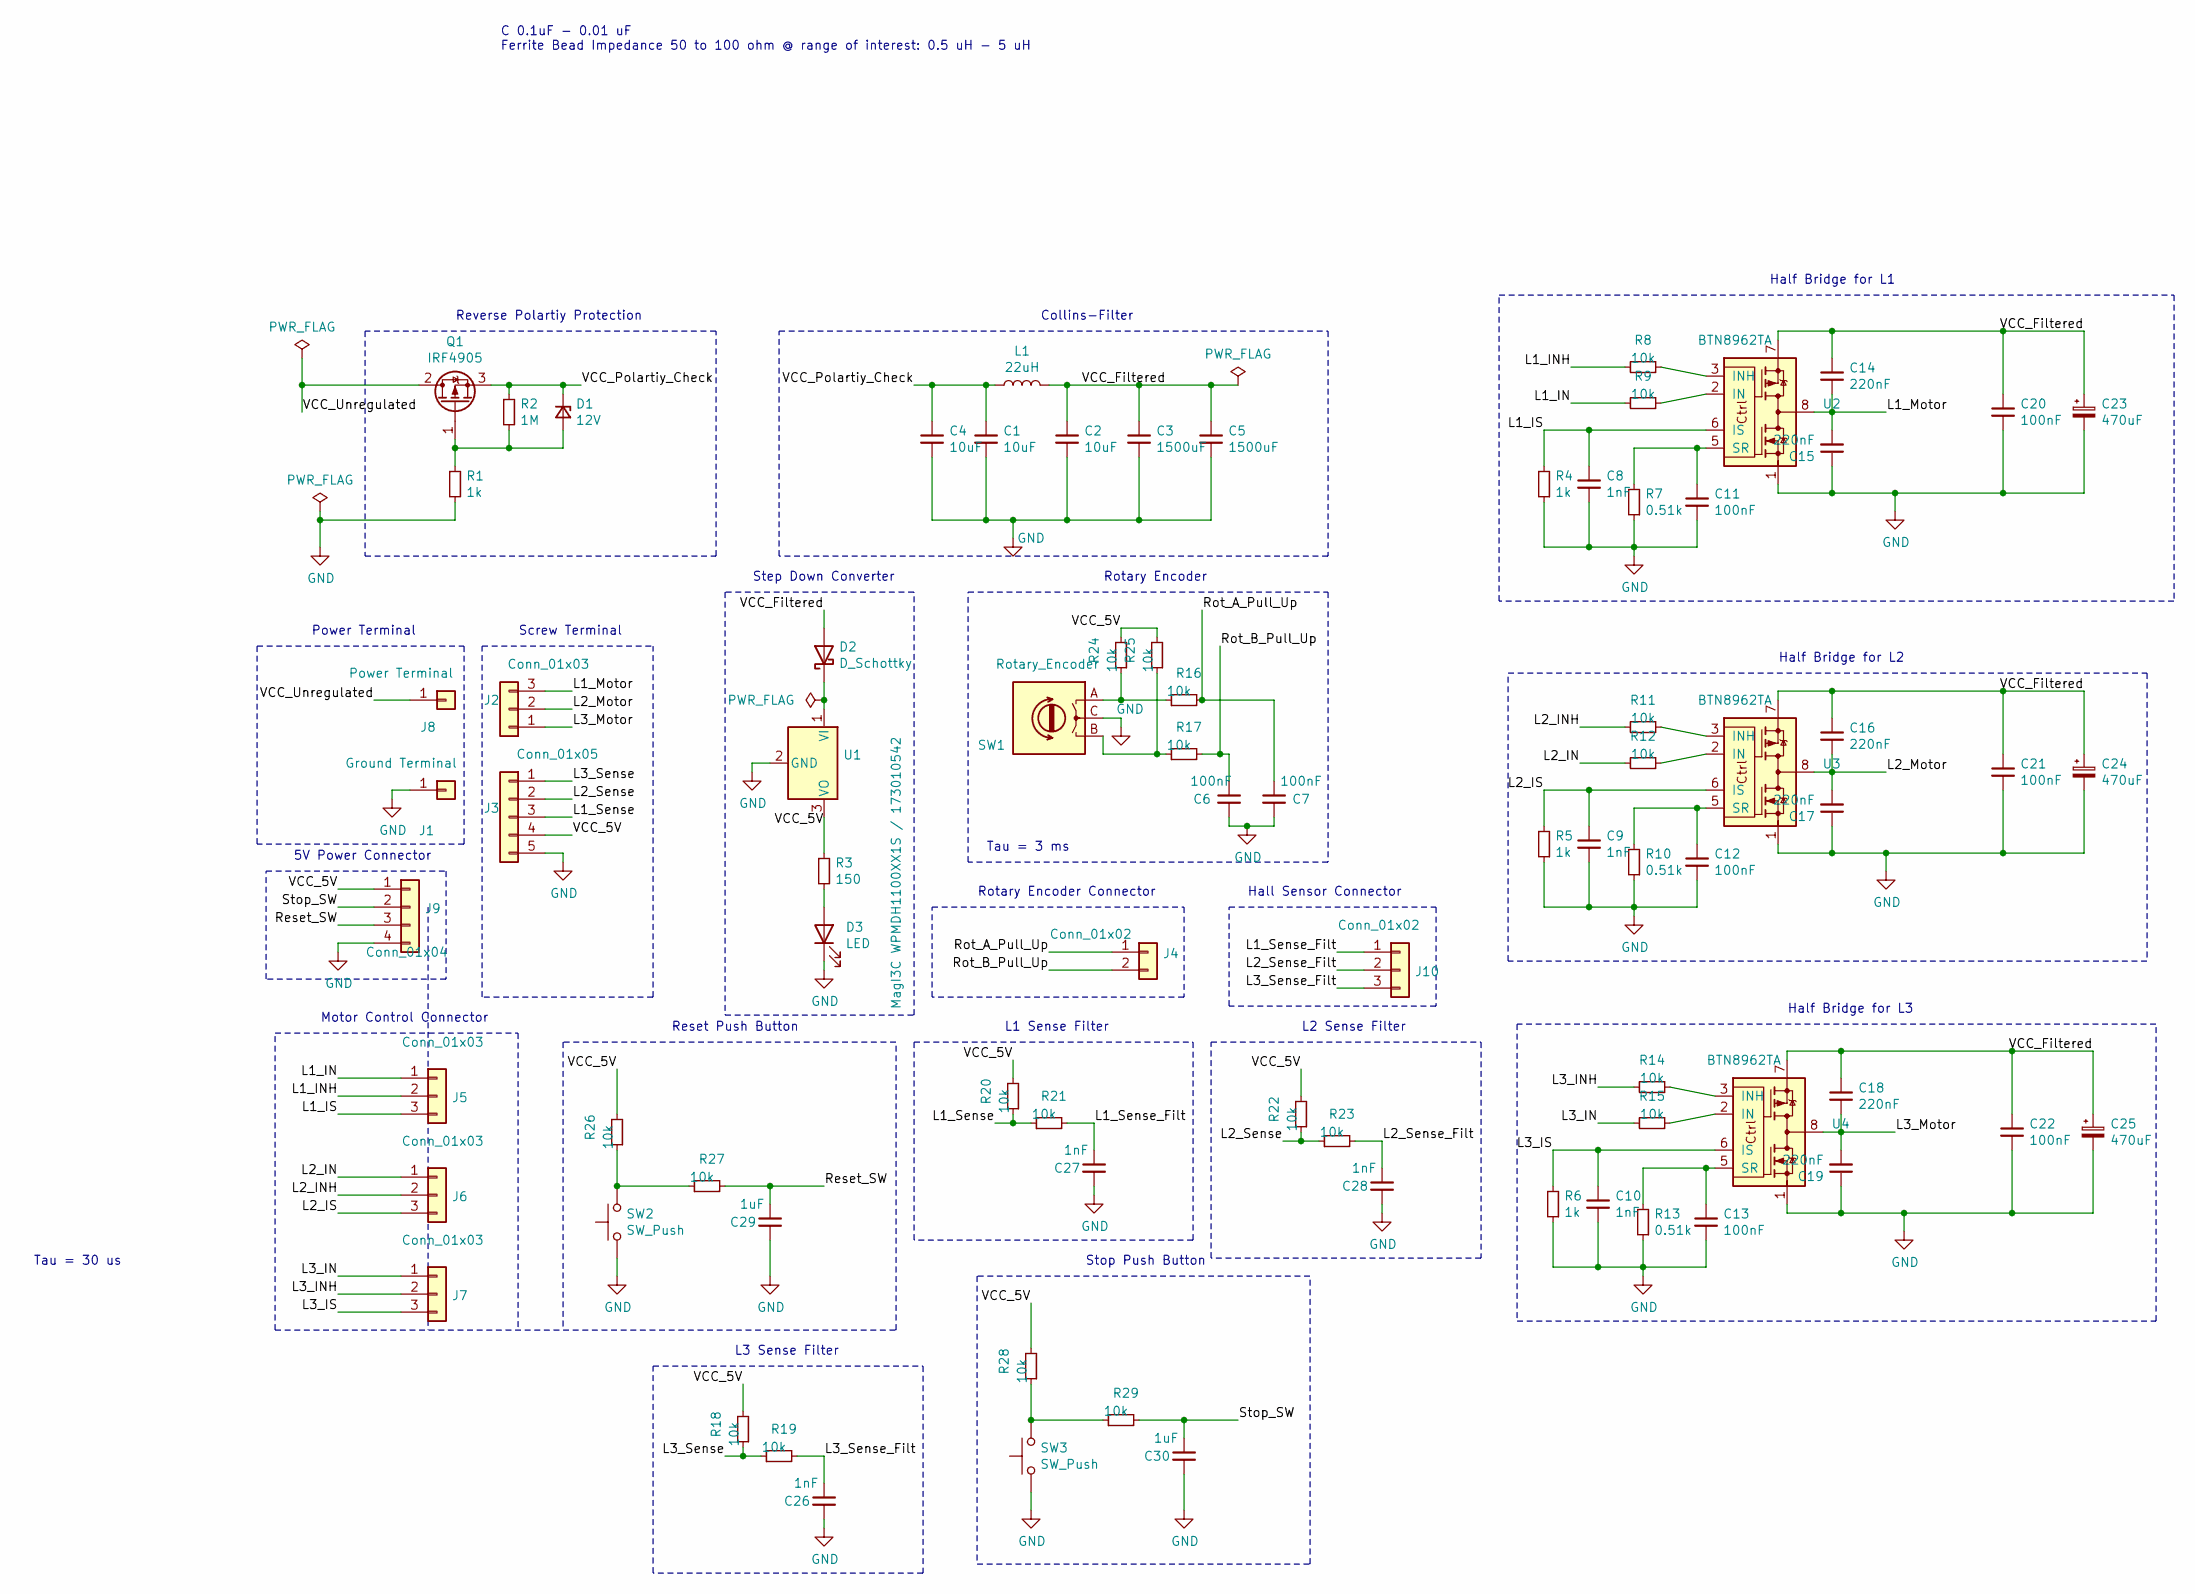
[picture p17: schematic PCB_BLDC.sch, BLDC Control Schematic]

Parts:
C1, C2, C4: 10uF; C_1210_3225Metric_Pad1.33x2.70mm_HandSolder
C3, C5: 1500uF; CP_Elec_16x17.5
C6, C7, C11, C12, C13, C20, C21, C22: 100nF; C_1206_3216Metric_Pad1.33x1.80mm_HandSolder
C8, C9, C10, C26, C27, C28: 1nF; C_1206_3216Metric_Pad1.33x1.80mm_HandSolder
C14, C15, C16, C17, C18, C19: 220nF; C_1206_3216Metric_Pad1.33x1.80mm_HandSolder
C23, C24, C25: 470uF; CP_Elec_16x17.5
C29, C30: 1uF; C_1206_3216Metric_Pad1.33x1.80mm_HandSolder
D1: 12V; D_SOD-123
D2: D_Schottky; D_SMB_Handsoldering
D3: LED; LED_1206_3216Metric_Pad1.42x1.75mm_HandSolder
J1: Ground Terminal; CalTest_CT3151
J2: Conn_01x03; TerminalBlock_Phoenix_MKDS-1,5-3_1x03_P5.00mm_Horizontal
J3: Conn_01x05; TerminalBlock_Phoenix_MKDS-1,5-5_1x05_P5.00mm_Horizontal
J4: Conn_01x02; PinSocket_1x02_P2.54mm_Vertical
J5, J6, J7: Conn_01x03; PinSocket_1x03_P2.54mm_Vertical
J8: Power Terminal; CalTest_CT3151
J9: Conn_01x04; PinSocket_1x04_P2.54mm_Vertical
J10: Conn_01x02; PinSocket_1x03_P2.54mm_Vertical
L1: 22uH; L_Wuerth_WE-PD-Typ-LS_Handsoldering
Q1: IRF4905; TO-263-2
R1, R4, R5, R6: 1k; R_1206_3216Metric_Pad1.30x1.75mm_HandSolder
R2: 1M; R_1206_3216Metric_Pad1.30x1.75mm_HandSolder
R3: 150; R_1206_3216Metric_Pad1.30x1.75mm_HandSolder
R7, R10, R13: 0.51k; R_1206_3216Metric_Pad1.30x1.75mm_HandSolder
R8, R9, R11, R12, R14, R15, R16, R17, R18, R19, R20, R21, R22, R23, R24, R25, R26, R27, R28, R29: 10k; R_1206_3216Metric_Pad1.30x1.75mm_HandSolder
SW1: Rotary_Encoder; RotaryEncoder_Alps_EC12E-Switch_Vertical_H20mm
SW2, SW3: SW_Push; SW_PUSH-12mm_Wuerth-430476085716
U1: MagI3C WPMDH1100XX1S / 173010542; SIP3_11.6x8.5mm
U2, U3, U4: BTN8962TA; TO-263-7_TabPin8

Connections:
/L1_IN: J5.1, R9.2
/L1_INH: J5.2, R8.2
/L1_IS: C8.1, J5.3, R4.2, U2.6 (IS)
/L1_Motor: C14.2, C15.2, J2.3, U2.4, U2.8
/L1_Sense: J3.3, R20.1, R21.1
/L1_Sense_Filt: C27.1, J10.1, R21.2
/L2_IN: J6.1, R12.2
/L2_INH: J6.2, R11.2
/L2_IS: C9.1, J6.3, R5.2, U3.6 (IS)
/L2_Motor: C16.2, C17.2, J2.2, U3.4, U3.8
/L2_Sense: J3.2, R22.1, R23.1
/L2_Sense_Filt: C28.1, J10.2, R23.2
/L3_IN: J7.1, R15.2
/L3_INH: J7.2, R14.2
/L3_IS: C10.1, J7.3, R6.2, U4.6 (IS)
/L3_Motor: C18.2, C19.2, J2.1, U4.4, U4.8
/L3_Sense: J3.1, R18.1, R19.1
/L3_Sense_Filt: C26.1, J10.3, R19.2
/Reset_SW: C29.1, J9.3, R27.2
/Rot_A_Pull_Up: C7.1, J4.1, R16.2
/Rot_B_Pull_Up: C6.1, J4.2, R17.2
/Stop_SW: C30.1, J9.2, R29.2
/VCC_5V: J3.4, J9.1, R3.1, R18.2, R20.2, R22.2, R24.2, R25.2, R26.2, R28.2, U1.3 (VO)
/VCC_Filtered: C2.1, C3.1, C5.1, C14.1, C16.1, C18.1, C20.1, C21.1, C22.1, C23.1, C24.1, C25.1, D2.2 (A), L1.2, U2.7, U3.7, U4.7
/VCC_Polartiy_Check: C1.1, C4.1, D1.1 (K), L1.1, Q1.3 (S), R2.1
/VCC_Unregulated: J8.1, Q1.2 (D)
GND: C1.2, C2.2, C3.2, C4.2, C5.2, C6.2, C7.2, C8.2, C9.2, C10.2, C11.2, C12.2, C13.2, C15.1, C17.1, C19.1, C20.2, C21.2, C22.2, C23.2, C24.2, C25.2, C26.2, C27.2, C28.2, C29.2, C30.2, D3.1 (K), J1.1, J3.5, J9.4, R1.2, R4.1, R5.1, R6.1, R7.1, R10.1, R13.1, SW1.C, SW2.1, SW3.1, U1.2 (GND), U2.1, U3.1, U4.1
unnamed: C11.1, R7.2, U2.5 (SR)
unnamed: C12.1, R10.2, U3.5 (SR)
unnamed: C13.1, R13.2, U4.5 (SR)
unnamed: D1.2 (A), Q1.1 (G), R1.1, R2.2
unnamed: D2.1 (K), U1.1 (VI)
unnamed: D3.2 (A), R3.2
unnamed: R8.1, U2.3 (INH)
unnamed: R9.1, U2.2 (IN)
unnamed: R11.1, U3.3 (INH)
unnamed: R12.1, U3.2 (IN)
unnamed: R14.1, U4.3 (INH)
unnamed: R15.1, U4.2 (IN)
unnamed: R16.1, R24.1, SW1.A
unnamed: R17.1, R25.1, SW1.B
unnamed: R26.1, R27.1, SW2.2
unnamed: R28.1, R29.1, SW3.2

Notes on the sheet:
C 0.1uF - 0.01 uF Ferrite Bead Impedance 50 to 100 ohm @ range of interest: 0.5 uH - 5 uH
Collins-Filter
Reverse Polartiy Protection
Half Bridge for L1
Screw Terminal
Rotary Encoder
Step Down Converter
Half Bridge for L2
Half Bridge for L3
Tau = 30 us
Tau = 3 ms
Power Terminal
5V Power Connector
Rotary Encoder Connector
Motor Control Connector
Reset Push Button
Hall Sensor Connector
L2 Sense Filter
L3 Sense Filter
L1 Sense Filter
Stop Push Button

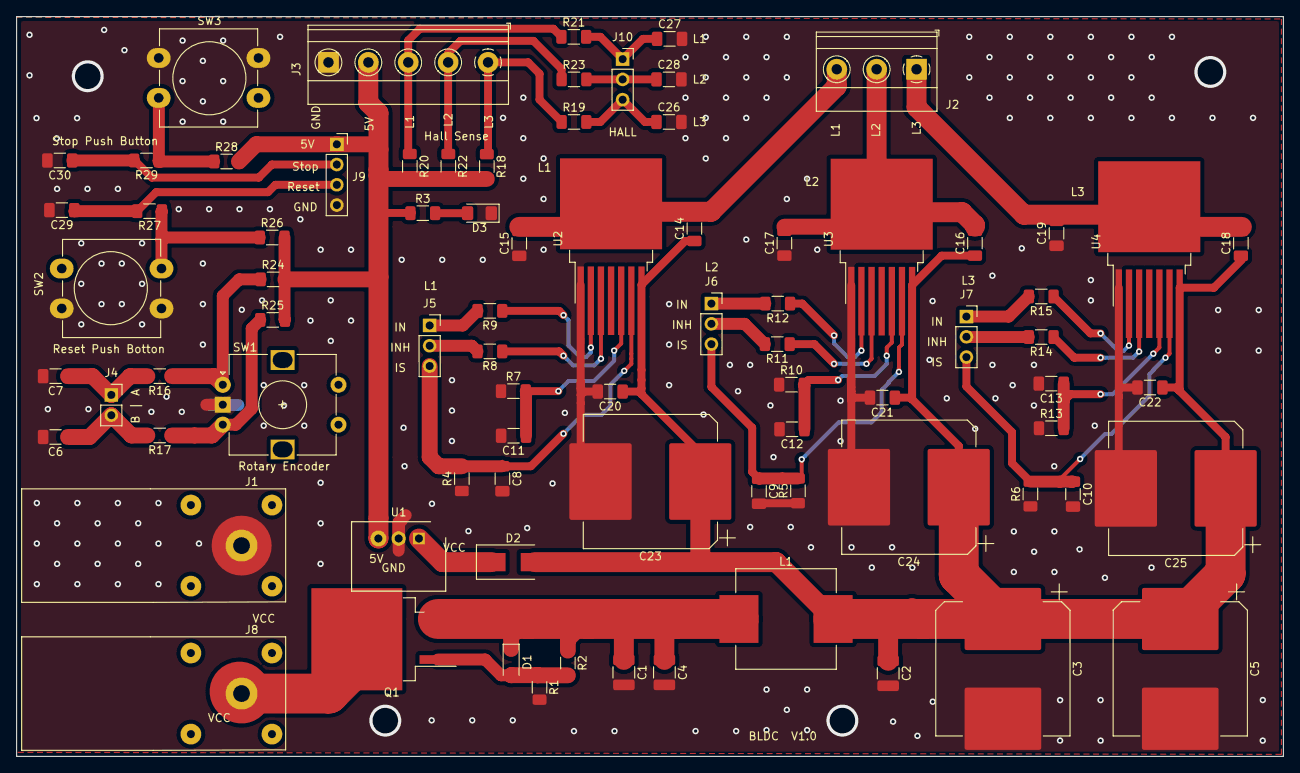
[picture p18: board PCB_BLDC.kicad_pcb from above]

Board: 2 copper layers, 158.8 x 92.7 mm, 81 parts (0 on the bottom side), 43 nets.

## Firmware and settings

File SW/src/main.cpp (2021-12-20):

// Open Loop Control
//////////////////////////////////////////////////////////////////////////////////////

// #include "main.hpp"

// void (*pReset_target_speed)(void) = reset_target_speed;

// void (*restart_motor)(void) = Motor_Implementation::start_motor_control;

// float (*desired_speed)(void) = getTargetSpeed;

// //  Motor_Implementation *Abstarct_motor;

// void setup() 
// {
//   Serial.begin(115200);
// Serial.println("1 Main Setup");
// _delay(100);

//   // Open_Loop *Abstract_motor = new Open_Loop;
// Closed_Loop *Abstract_motor = new Closed_Loop;
// _delay(100);
// Serial.println("2");
//   // Abstarct_motor = new Open_Loop;
//   // Closed_Loop Abstract_motor;

//   Abstract_motor->motor_implementation_init();
// Serial.println("3 Setup");
//   init_button(pReset_target_speed);

//   while(1)
//   {
//   read_buttons(restart_motor); 
//   Abstract_motor->motor_control(desired_speed());
//   }
// }

////////////////////////////////////////////////////////////////////////////////////////////

/**
 *
 * Velocity motion control example
 * Steps:
 * 1) Configure the motor and sensor
 * 2) Run the code
 * 3) Set the target velocity (in radians per second) from serial terminal
 *
 *
 *
 * NOTE :
 * > Specifically for Arduino UNO example code for running velocity motion control using a hall sensor
 * > Since Arduino UNO doesn't have enough interrupt pins we have to use software interrupt library PciManager.
 *
 * > If running this code with Nucleo or Bluepill or any other board which has more than 2 interrupt pins
 * > you can supply doC directly to the sensor.enableInterrupts(doA,doB,doC) and avoid using PciManger
 *
 */

// Closed Loop Control

#include "pin_config.hpp"
#include "button_implementation/button_implementation.hpp"
#include "encoder_implementation/encoder_implementation.hpp"

#include <SimpleFOC.h>
// software interrupt library
#include <PciManager.h>
#include <PciListenerImp.h>

// BLDC motor & driver instance
BLDCMotor motor = BLDCMotor(11);
BLDCDriver3PWM driver = BLDCDriver3PWM(9, 10, 11, 6);
// Stepper motor & driver instance
//StepperMotor motor = StepperMotor(50);
//StepperDriver4PWM driver = StepperDriver4PWM(9, 5, 10, 6,  8);

// hall sensor instance
HallSensor sensor = HallSensor(2, 3, 4, 11);

InlineCurrentSense currentsense(1, 1, IS0, IS1, IS2);;

void (*pReset_target_speed)(void) = reset_target_speed;
float (*desired_speed)(void) = getTargetSpeed;
void restart_motor(void)
{
  digitalWrite(INH, true);
}


// Interrupt routine intialisation
// channel A and B callbacks
void doA(){sensor.handleA();}
void doB(){sensor.handleB();}
void doC(){sensor.handleC();}
// If no available hadware interrupt pins use the software interrupt
PciListenerImp listenerIndex(sensor.pinC, doC);

// velocity set point variable
float target_velocity = 0;
// instantiate the commander
Commander command = Commander(Serial);
void doTarget(char* cmd) { command.scalar(&target_velocity, cmd); }

void setup() {

  // initialize sensor sensor hardware
  sensor.init();
  sensor.enableInterrupts(doA, doB); //, doC);
  // software interrupts
  PciManager.registerListener(&listenerIndex);
  // link the motor to the sensor
  motor.linkSensor(&sensor);

  currentsense.init();

  // driver config
  // power supply voltage [V]
  driver.voltage_power_supply = 12;
  driver.init();
  // link the motor and the driver
  motor.linkDriver(&driver);

  // aligning voltage [V]
  motor.voltage_sensor_align = 3;

  // set motion control loop to be used
  motor.controller = MotionControlType::velocity;

  // contoller configuration
  // default parameters in defaults.h

  // velocity PI controller parameters
  motor.PID_velocity.P = 0.2f;
  motor.PID_velocity.I = 2;
  motor.PID_velocity.D = 0;
  // default voltage_power_supply
  motor.voltage_limit = 12;
  // jerk control using voltage voltage ramp
  // default value is 300 volts per sec  ~ 0.3V per millisecond
  motor.PID_velocity.output_ramp = 1000;
  motor.velocity_limit = 500; // [rad/s] cca 500rpm
  motor.current_limit = 200; // 2 A 

  // velocity low pass filtering time constant
  motor.LPF_velocity.Tf = 0.01f;

  // use monitoring with serial
  Serial.begin(115200);
  // comment out if not needed
  // motor.useMonitoring(Serial);
motor.linkCurrentSense(&currentsense);     // include this function 
  // initialize motor
  motor.init();
  // align sensor and start FOC
  motor.initFOC();

  // add target command T
  // command.add('T', doTarget, "target voltage");

  Serial.println(F("Motor ready."));
  Serial.println(F("Set the target velocity using serial terminal:"));

    init_button(pReset_target_speed);

  _delay(1000);
}


void loop() {
  // main FOC algorithm function
  // the faster you run this function the better
  // Arduino UNO loop  ~1kHz
  // Bluepill loop ~10kHz
  motor.loopFOC();

  // Motion control function
  // velocity, position or voltage (defined in motor.controller)
  // this function can be run at much lower frequency than loopFOC() function
  // You can also use motor.move() and set the motor.target in the code
  motor.move(target_velocity);

  // function intended to be used with serial plotter to monitor motor variables
  // significantly slowing the execution down!!!!
  // motor.monitor();
  read_buttons(restart_motor); 
  target_velocity = desired_speed();
  // user communication
  // command.run();
}

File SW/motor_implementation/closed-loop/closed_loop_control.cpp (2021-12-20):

#include "closed_loop_control.hpp"
#include "pin_config.hpp"

HallSensor *pSensor;
//  HallSensor sensor(2, 3, 4, 3);
//  HallSensor *pSensor = &sensor;
//  PciManager *manager = new PciManager();
InlineCurrentSense* currentsense;

Closed_Loop::Closed_Loop()
    :Motor_Implementation()
{

 listenerIndex = new PciListenerImp(pSensor->pinC, doC); 
//  currentsense= new InlineCurrentSense (1, 1, IS0, IS1, IS2);
}

Closed_Loop::Closed_Loop(BLDCMotor *ext_motor, BLDCDriver3PWM *ext_driver)
  :Motor_Implementation(motor, driver)
{
  // tbd
}

 void Closed_Loop::motor_implementation_init(void)
 {
   Serial.println("Pre_Init");

  pSensor = new HallSensor(2, 3, 4, 11);
  //  currentsense->init();
  pSensor->init();
  pSensor->enableInterrupts(doA, doB); //, doC);
  // software interrupts
  PciManager.registerListener(listenerIndex);
  // link the motor to the sensor
  motor->linkSensor(pSensor);
  driver->voltage_power_supply = 12;
  driver->init();
  motor->linkDriver(driver);
  motor->voltage_sensor_align = 3;
  motor->controller = MotionControlType::velocity;
  motor->PID_velocity.P = 1.0f;
  motor->PID_velocity.I = 0.01;
  motor->PID_velocity.D = 0;
  motor->voltage_limit = 6;

  // jerk control using voltage voltage ramp
  // default value is 300 volts per sec  ~ 0.3V per millisecond
  motor->PID_velocity.output_ramp = 10;

  // velocity low pass filtering time constant
  motor->LPF_velocity.Tf = 0.01f;

  motor->init();
  motor->initFOC();
  // motor->linkCurrentSense(currentsense);     // include this function 
_delay(1000);
Serial.println("Init done");
}















    void doA()
    {
        pSensor->handleA();
        // Serial.println("Reading Sensor A");
    }

    void doB()
    {
        pSensor->handleB();
    }
    
    void doC()
    {
        pSensor->handleC();
    }

// Closed_Loop::
void Closed_Loop::motor_control(float velocity)
{
  // Serial.println("Executing Regelung");
  motor->loopFOC();
  motor->move(velocity);
}

Closed_Loop::~Closed_Loop()
{
  delete pSensor;
  delete currentsense;
}

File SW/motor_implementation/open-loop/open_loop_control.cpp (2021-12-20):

#include "open_loop_control.hpp"

Open_Loop::Open_Loop(BLDCMotor *ext_motor, BLDCDriver3PWM *ext_driver)
  :Motor_Implementation(motor, driver)
{

}

Open_Loop::Open_Loop()
  :Motor_Implementation()
{

}



void Open_Loop::motor_implementation_init(void)
{
  driver->voltage_power_supply = 12;
  driver->init();
  // link the motor and the driver
  motor->linkDriver(driver);

  // limiting motor movements
  motor->voltage_limit = 3;   // [V]
  motor->velocity_limit = 5; // [rad/s] cca 500rpm


    // open loop control config
  motor->controller = MotionControlType::velocity_openloop;

  // init motor hardware
  motor->init();
  Serial.println("Motor ready!");
  Serial.println("Set target velocity [rad/s]");
  _delay(1000);
}


void Open_Loop::motor_control(float velocity)
{
  motor->move(velocity);
}

Open_Loop::~Open_Loop()
{

}

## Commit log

2021-10-21 Main: Inital Commit for BLDC Project
2021-10-21 Main: Start Schmeatic Layout
    [PCB_BLDC.kicad_pcb, PCB_BLDC.sch]
2021-10-22 Main: Update Schematic Start PCB-Layout
    [PCB_BLDC.kicad_pcb, PCB_BLDC.sch]
2021-10-29 Main: Improve Schematic
    [PCB_BLDC.kicad_pcb, PCB_BLDC.sch]
2021-10-29 Main: Update Schematic
    [PCB_BLDC.kicad_pcb, PCB_BLDC.sch]
2021-10-30 Main: Update Schmeatics and PCB
    [PCB_BLDC.kicad_pcb, PCB_BLDC.sch]
2021-10-31 Main: Trace Routing @ PCB
    [PCB_BLDC.kicad_pcb, PCB_BLDC.sch]
2021-11-01 Main: Update Footprint, PCB Layout
    [Infineon_PG-LLGA-5-1.FCStd, L_Coilcraft_LPS5030.FCStd, L_Wuerth_WE-TPC-3816.FCStd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]
2021-11-01 Main: Update Schmeatics, Add VCC
    [PCB_BLDC.kicad_pcb]
2021-11-04 Main: Update Arduino Pins, PCB Routing
    [PCB_BLDC.kicad_pcb, PCB_BLDC.sch]
2021-11-05 Main: Update Routing, Schmematic to use Analog Ports of Arduino
    [PCB_BLDC.kicad_pcb, PCB_BLDC.sch]
2021-11-06 Main: Finish PCB Routing Add Filled Zone Texts
    [PCB_BLDC.kicad_pcb, PCB_BLDC.sch]
2021-11-06 Main: Add Text to Schematic and PCB, Images
    [PCB_BLDC.kicad_pcb, PCB_BLDC.sch]
2021-11-06 PCB: Add Images, PDFs, Gerber-Files
    [PCB_BLDC-B_Cu.gbl, PCB_BLDC-B_Mask.gbs, PCB_BLDC-B_Paste.gbp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]
2021-11-06 Main: Update PCB, Add Vias, Update Schematic, Update Netlist
    [PCB_BLDC.csv, PCB_BLDC.kicad_pcb, PCB_BLDC.sch]
2021-11-08 PCB: New PCB without Arduino and smaaler size made
    [PCB_BLDC-B_Cu.gbl, PCB_BLDC-B_Mask.gbs, PCB_BLDC-B_Paste.gbp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]
2021-11-08 Main: Update Schematic, Add Vias, RC-Filt for Hall-Sense
    [PCB_BLDC-B_Cu.gbl, PCB_BLDC-B_Mask.gbs, PCB_BLDC-B_Paste.gbp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]
2021-11-09 PCB: Fixed again Low Pass Filter
    [PCB_BLDC.kicad_pcb, PCB_BLDC.sch]
2021-11-12 PCB: Changed Power Terminals to correct one, Adapted csv-File to PT1-Filter
    [PCB_BLDC.csv, PCB_BLDC.kicad_pcb, PCB_BLDC.sch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]
2021-11-13 Minor adjustments @ THT size csv and resistor values
    [PCB_BLDC.csv, PCB_BLDC.kicad_pcb, Wuerth_list.csv]
2021-11-14 Add Push Button to Reset the System
    [PCB_BLDC.kicad_pcb, PCB_BLDC.sch, Wuerth_list.csv]
2021-11-14 PCB: Change Position of RC Filt for Hall Sense and Position of Connector
    [PCB_BLDC.kicad_pcb, PCB_BLDC.sch]
2021-11-15 PCB: Add *.pdf and update gerber files
    [PCB_BLDC-B_Cu.gbl, PCB_BLDC-B_Mask.gbs, PCB_BLDC-B_Paste.gbp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]
2021-11-15 PCB: Final Review. Add new Push Button, Change wrong Capacitors Change Routing, Add Mounting Holes
    [PCB_BLDC.kicad_pcb, PCB_BLDC.sch, Wuerth_list.csv]
2021-11-15 PCB: Add Image Output to view it easier
    [PCB_BLDC.csv, PCB_BLDC.sch]
2021-11-26 PCB: Fix Folder structure - Delete old design with arduino - Clean SW folder strucutre
    [PCB_BLDC-B_Cu.gbl, PCB_BLDC-B_Mask.gbs, PCB_BLDC-B_Paste.gbp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]
2021-11-26 SW: Make Working Digital Poti - Call Motor functions - TODO: Include .c files to platform.ini to sovle linking error
    [main.cpp]
2021-11-26 SW: Basic Open Loop setup for BLDC Motor Control
2021-11-27 SW: Add push button functionality
    - rework architecture
    [button_implementation.cpp, encoder_implementation.cpp, main.cpp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]
2021-11-27 Open Loop Motor Control is working
2021-11-28 SW_new_Architect: Update to OOP
    - L3 is behaving weiredly. Is counter acting 1 duty cicly, and 1 is ok
    - Current consume has doubled to 4-5 Amps
2021-11-28 SW_new_Architect: Fix bug which caused too long period for L3
    - Bug was probably caused by weired initialization:
    - Motor_Implementation was globally defined
    - was kind off preinitialized probably because it was on stack
    - start speed control with Hall sense
    [closed_loop_control.cpp, main.cpp, motor_implementation.cpp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]
2021-12-02 SW_new_Architecture: Add Control loop with PI Controller and current sense
    - Current Sense has to be finetuned with R_shunt and gain value
2021-12-02 SW_new_Architect: Fix correct init of Closed Loop
    - Motor behaves really weiredly, almost like angle control with extrem fast
    direction in change randomly, demands sometime very much current, without moving
    [closed_loop_control.cpp, encoder_implementation.cpp, main.cpp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]
2021-12-03 Closed Loop Control working with example script,
    - Paramter number polepairs and number hallsense wrongly set
    [closed_loop_control.cpp, main.cpp, motor_implementation.cpp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]
2021-12-04 SW_new_Architect: Add Current Sense with arbitrary values
    - Motor works as it is supposed to
2022-01-20 pyhton script for genertating sine wave start for hw Layer on stm32f446re
    [test.csv]
2022-01-22 STM SW with Class Strcuture for Motor
2022-01-30 Add Readme
    - gnerate Hall Files
2022-02-02 Update Hall module
2022-02-03 refactor code, abstarct motor_phase, generate sinusodal and bock_com refacotr motor_implementation
2022-02-03 refactor motor_implementation
